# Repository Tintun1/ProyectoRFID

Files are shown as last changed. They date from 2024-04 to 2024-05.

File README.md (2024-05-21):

# Proyecto RFID/NFC con App Web

Es una solución eficaz para cuando se necesita restringir el acceso a un área determinada y queremos tener la lista de usuarios permitidos en una base de datos segura con una aplicación web para la interfaz grafica del control de acceso.

## Participantes

- Fernandez Joaquín - Programación
- Lescano Cristian - Fabricación de PCB
- Lacuadra Catalina - Montaje y diseño
- Macre Geremias -  Montaje y diseño

## Aplicación

Para implementarlo como control de acceso a un área, necesitamos ajustar unos parámetros del microcontrolador, para que se pueda conectar a la red wifi



[https://github.com/Tintun1/ProyectoRFID/blob/main/Codigo ESP32/nfcReader/nfcReader.ino](https://github.com/Tintun1/ProyectoRFID/blob/main/Codigo%20ESP32/nfcReader/nfcReader.ino)

una vez configurado, el microcontrolador ya tendrá acceso a la red wifi.

Para poder vincular nuestra base de datos lo debemos hacer desde este archivo:

[https://github.com/Tintun1/ProyectoRFID/blob/main/AppWeb/con_db.php](https://github.com/Tintun1/ProyectoRFID/blob/main/AppWeb/con_db.php)



se debería de poner las credenciales correspondientes a la base de datos y en [https://github.com/Tintun1/ProyectoRFID/blob/main/AppWeb/ESP32/esp32_update.php](https://github.com/Tintun1/ProyectoRFID/blob/main/AppWeb/ESP32/esp32_update.php)

tendremos la API de la conexión de la base de datos con el microcontrolador que se puede modificar a gusto.

Para poder hacer funcionar  la aplicación web necesitaremos hostear nuestro servidor, una de las formas es usar XAMMP que nos facilita el host de la pagina de manera local

## Usos

Luego de configurar y ajustar los parámetros a nuestra comodidad, dispondremos de un control de acceso funcional. Lo único que hay que hacer para probar que funcione correctamente es verificar si el host de la pagina anda correctamente, registrando nuestros datos en la pagina para acceder a nuestro panel admin y poder registrar tarjetas nuevas a la base de datos, una vez registrada probar si el control de acceso lee nuestra tarjeta y que de la autorización.

## Esquemático

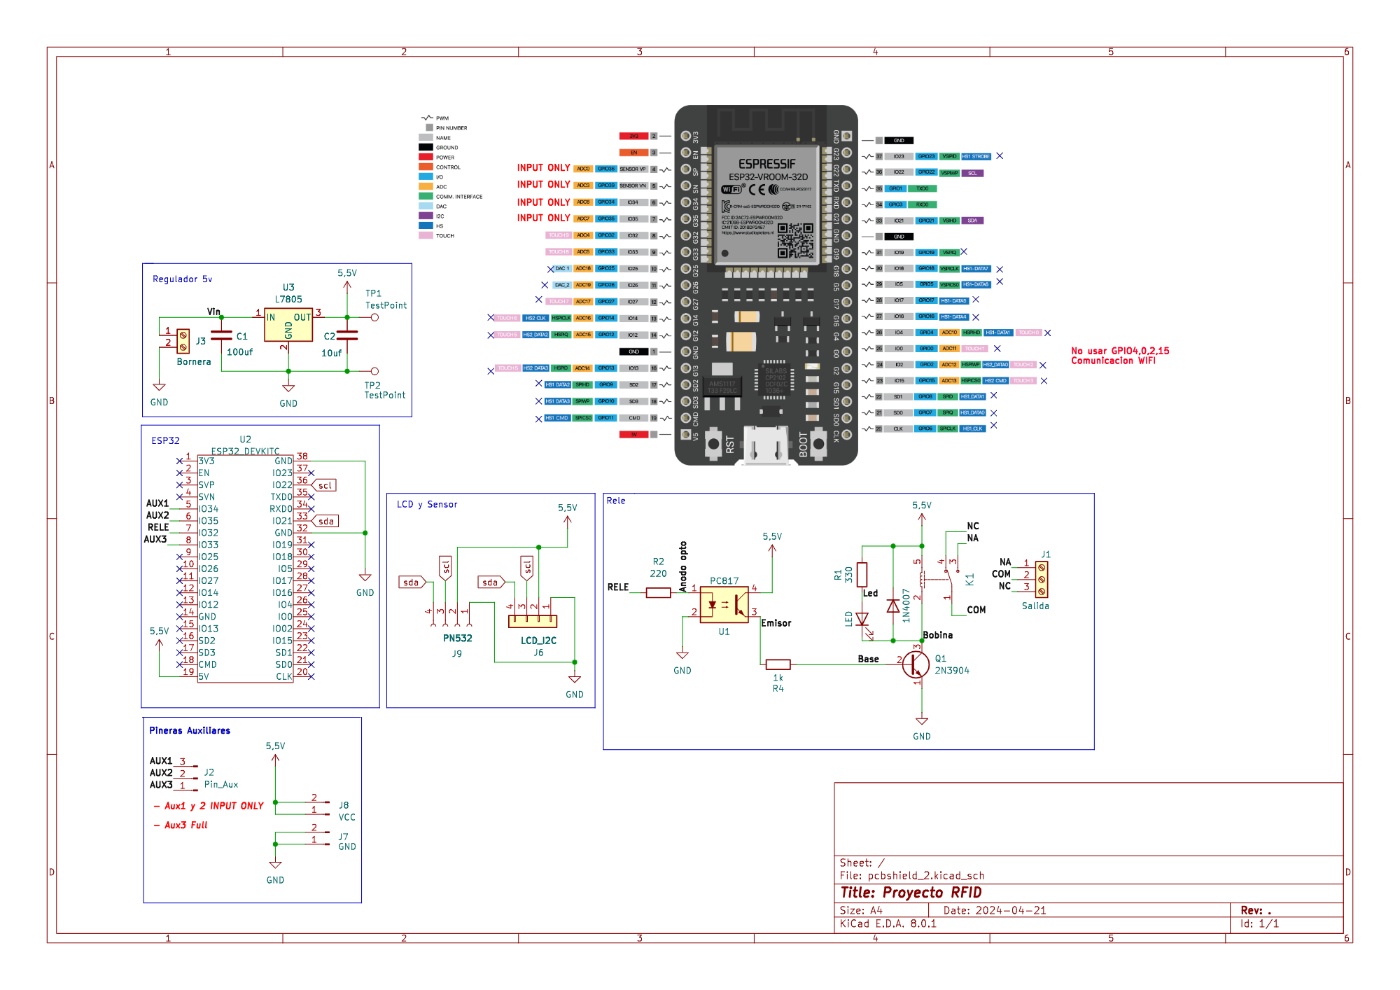
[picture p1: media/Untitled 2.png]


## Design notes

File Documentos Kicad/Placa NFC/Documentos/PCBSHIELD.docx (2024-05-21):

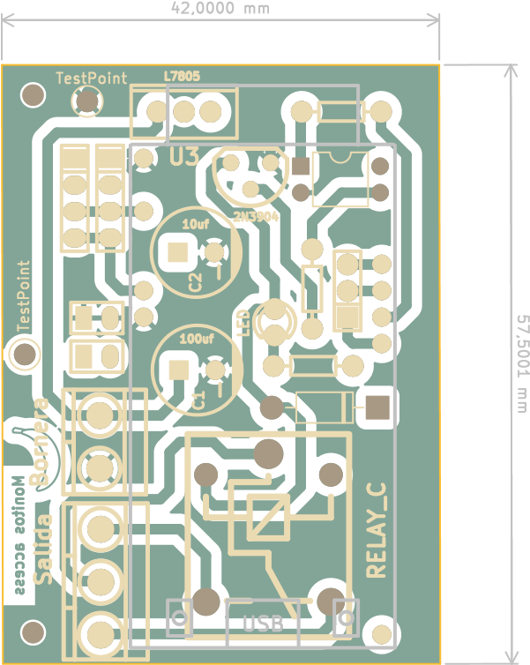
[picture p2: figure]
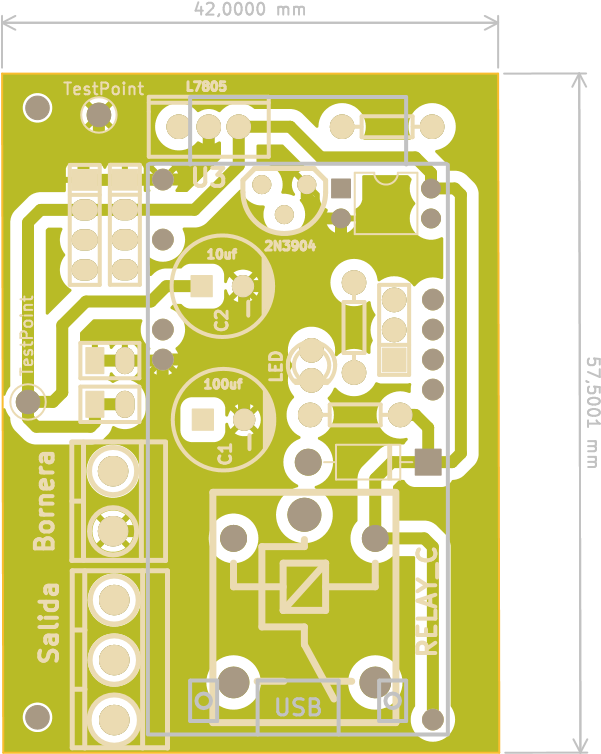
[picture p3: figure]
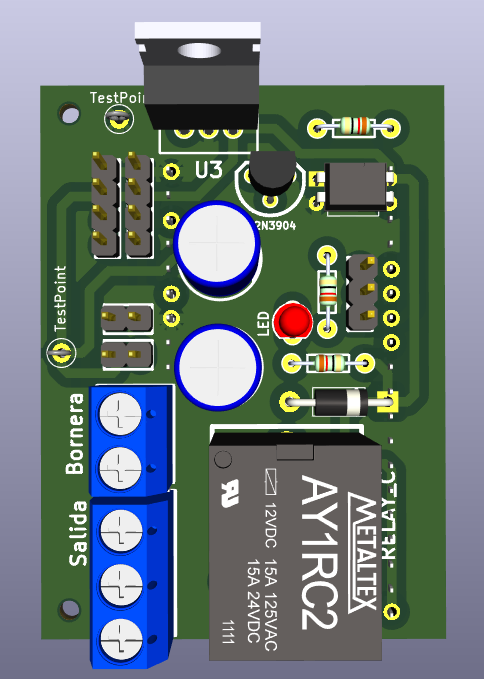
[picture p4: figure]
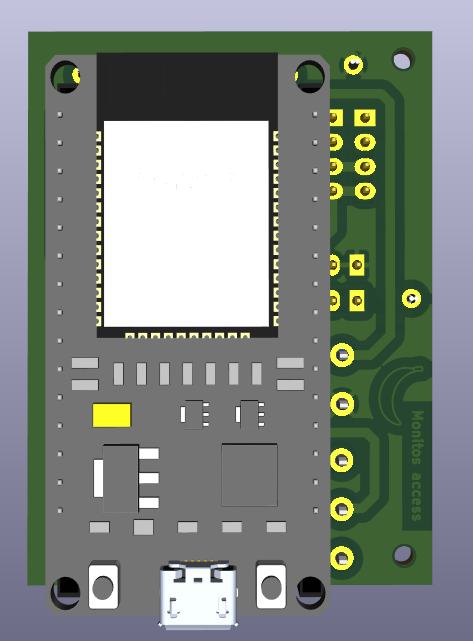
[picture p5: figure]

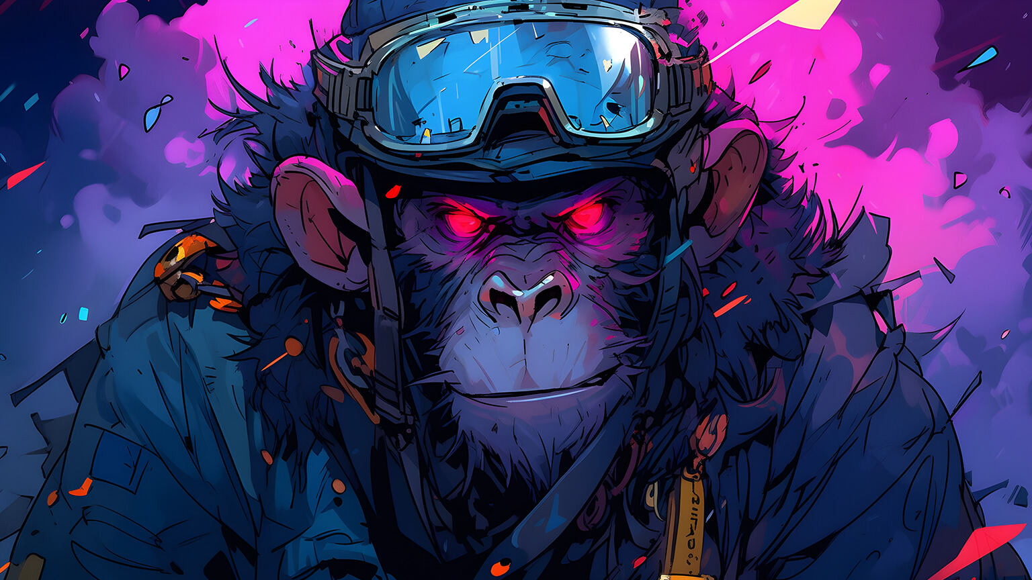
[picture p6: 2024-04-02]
AppWeb/img/monkey_background.jpg

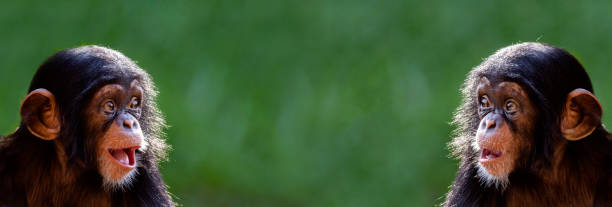
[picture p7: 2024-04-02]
AppWeb/img/input_back.jpg

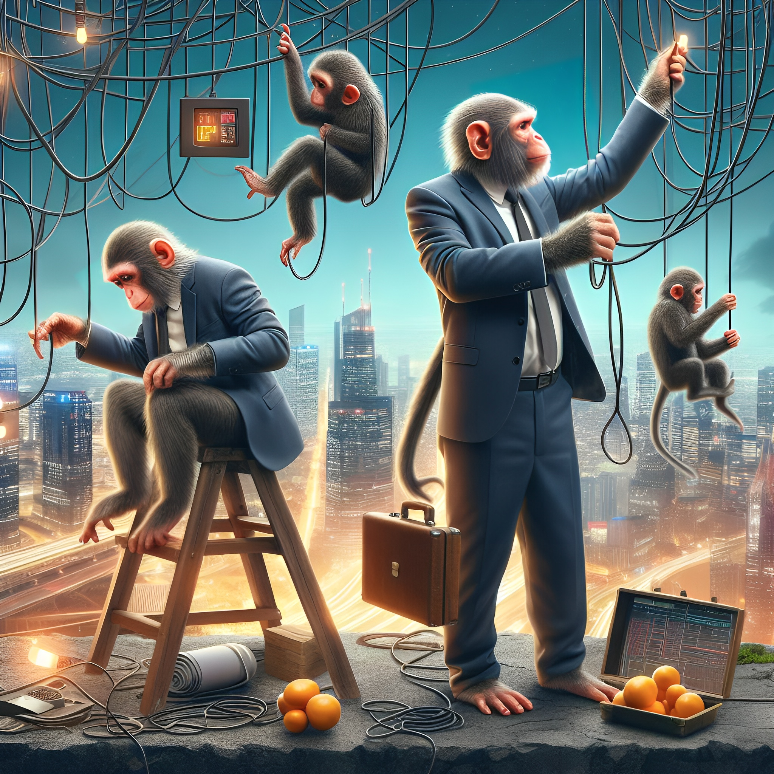
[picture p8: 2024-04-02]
AppWeb/img/background_img.jpg

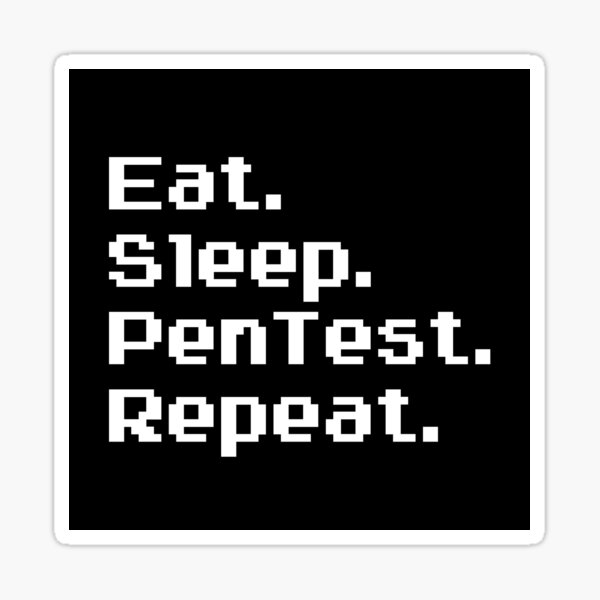
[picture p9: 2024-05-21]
AppWeb/uploads/st,small,507x507-pad,600x600,f8f8f8.u3.jpg

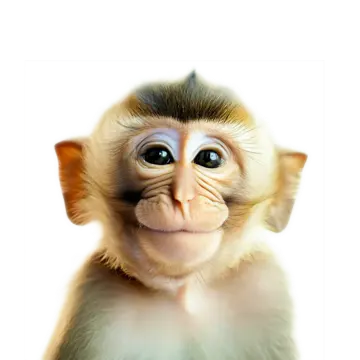
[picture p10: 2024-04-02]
AppWeb/uploads/pngtree-the-cute-monkey-on-transparent-png-image_6742881.png

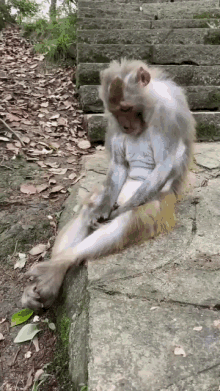
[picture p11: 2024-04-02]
AppWeb/uploads/mono-esperando_2.gif

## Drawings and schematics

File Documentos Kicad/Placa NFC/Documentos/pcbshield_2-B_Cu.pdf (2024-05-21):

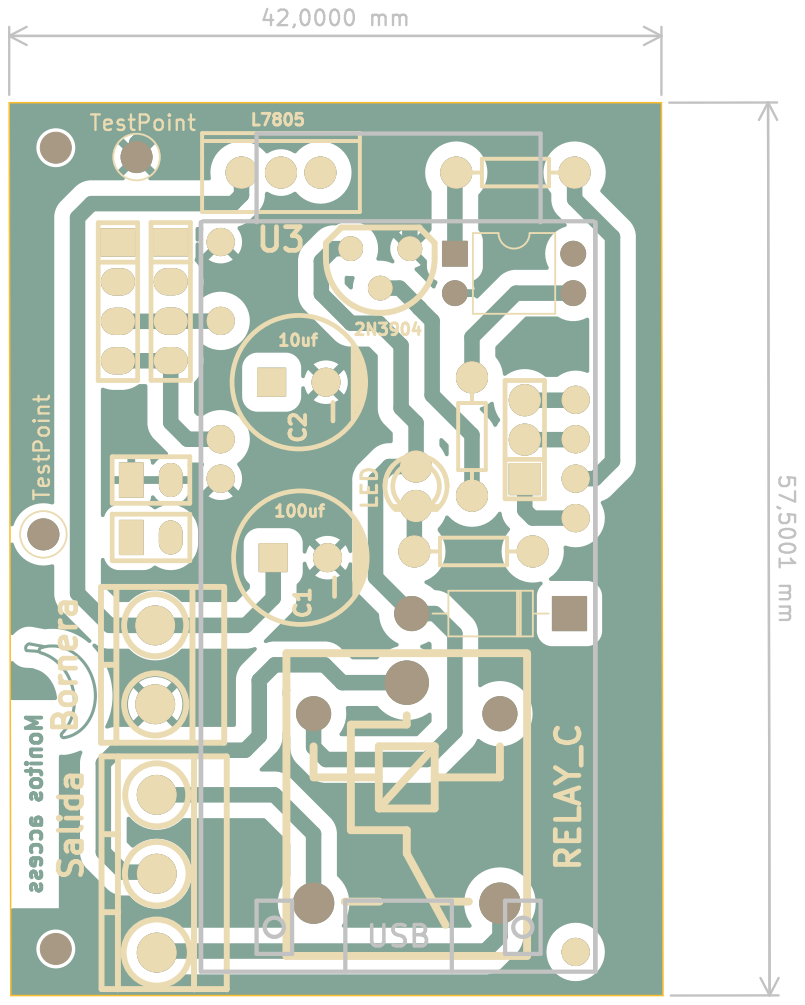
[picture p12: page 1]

Monitos access LED Salida RELAY_C C2

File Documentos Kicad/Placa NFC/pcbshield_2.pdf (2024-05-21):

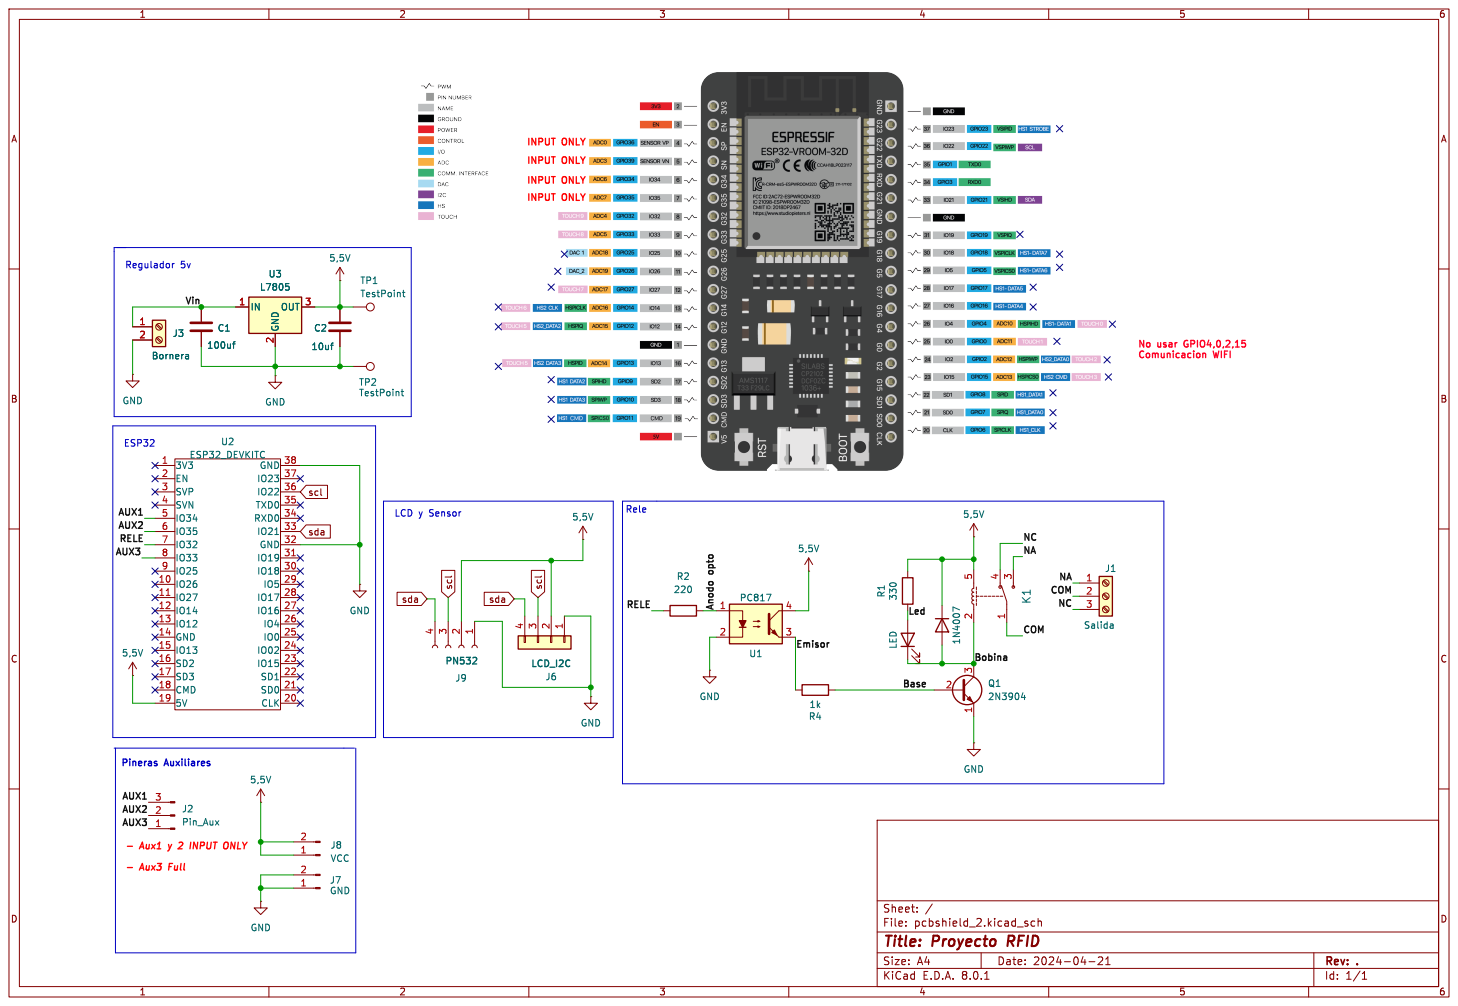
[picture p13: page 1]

Id: 1/1 Title: Proyecto RFID

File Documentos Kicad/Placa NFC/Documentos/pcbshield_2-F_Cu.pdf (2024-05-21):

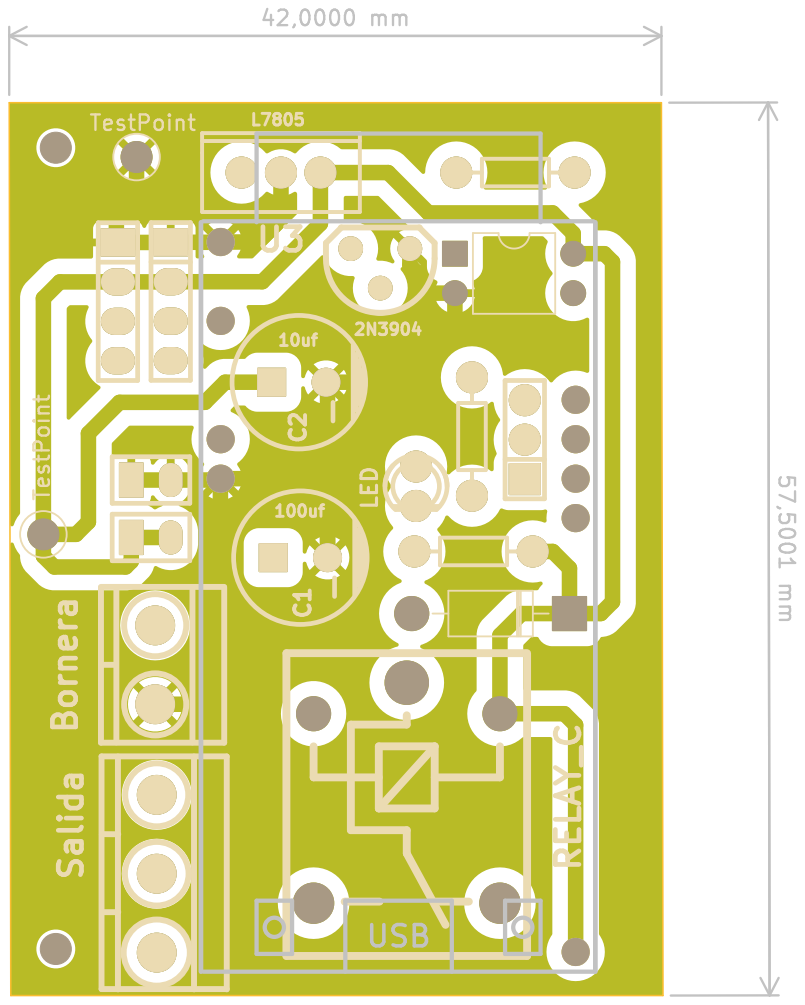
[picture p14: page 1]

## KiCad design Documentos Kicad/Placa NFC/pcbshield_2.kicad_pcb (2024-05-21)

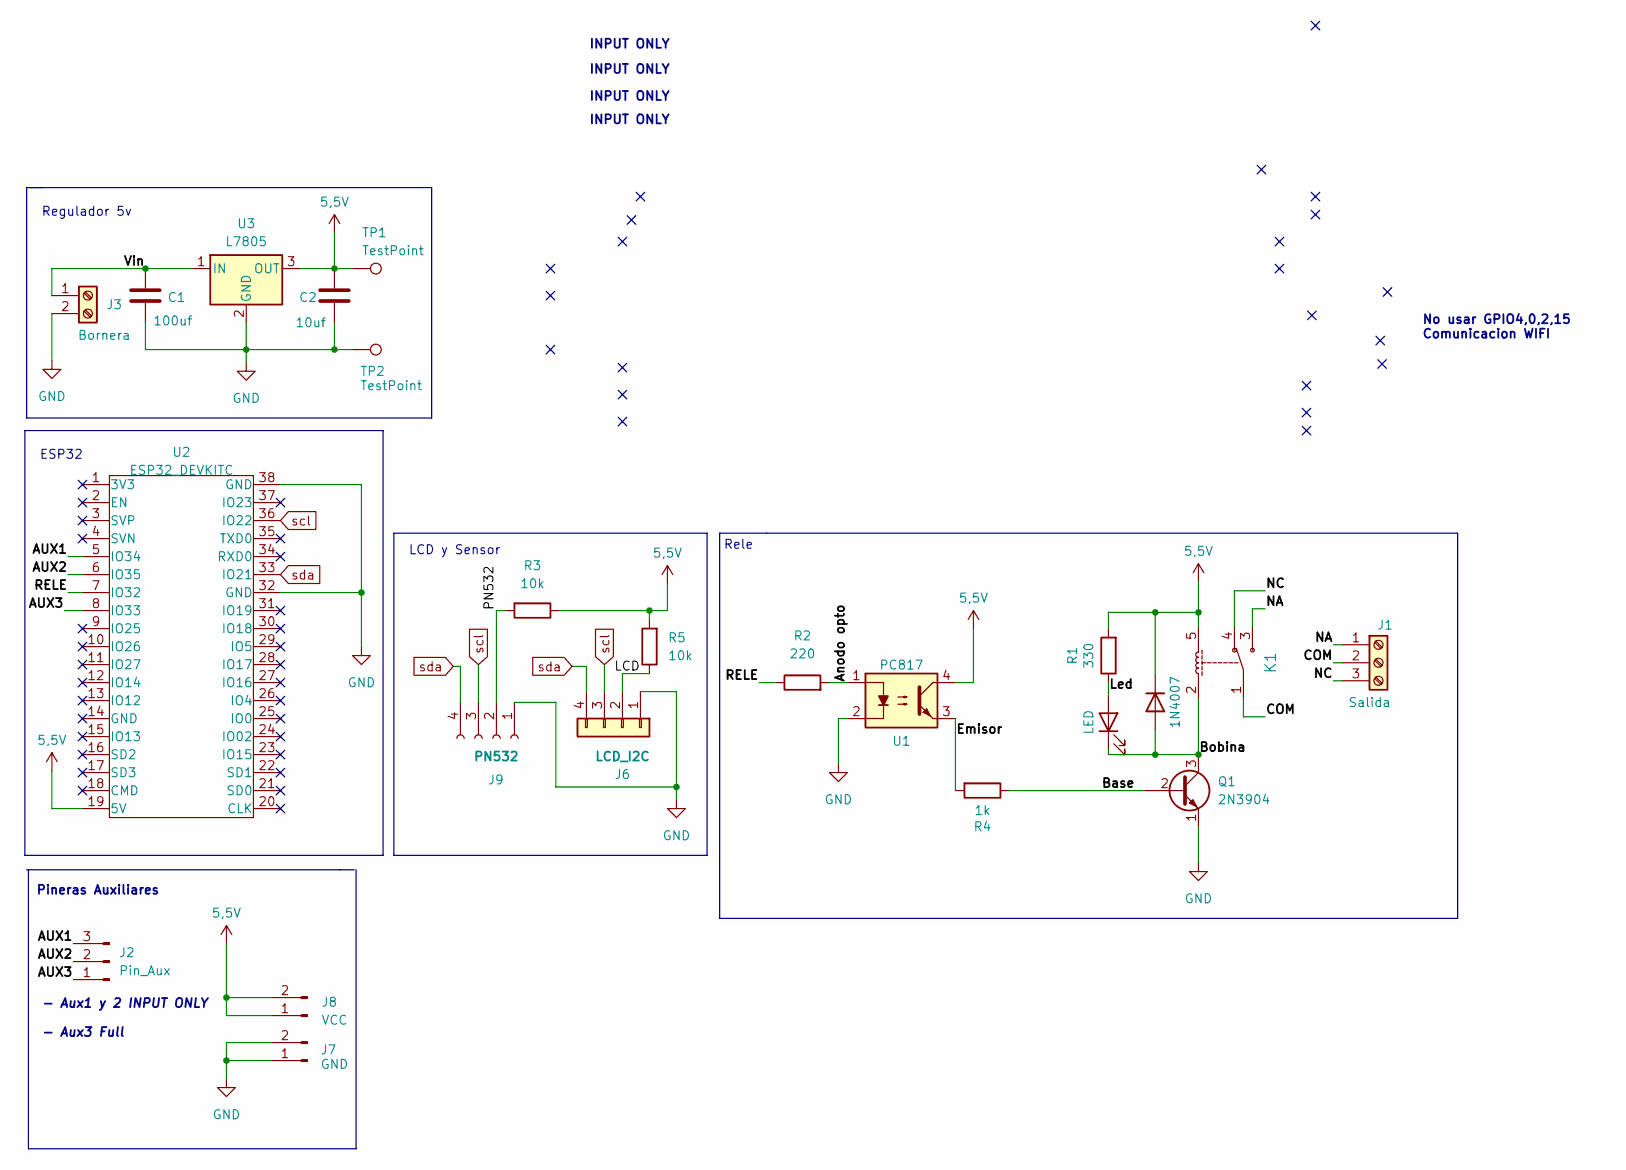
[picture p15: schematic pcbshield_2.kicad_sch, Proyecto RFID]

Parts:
C1: 100uf; CAP_ELEC_8x11.5mm
C2: 10uf; CAP_ELEC_8x11.5mm
D1: LED; led_3mm_red
D2: 1N4007; D_DO-41_SOD81_P10.16mm_Horizontal
J1: Salida; BORNERA3_AZUL
J2: Pin_Aux; Pin_Strip_3
J3: Bornera; BORNERA2_AZUL
J6: LCD_I2C; pin_strip_4
J7: GND; Pin_strip_2
J8: VCC; Pin_strip_2
J9: PN532; pin_strip_4
K1: RELAY_C; Relay_C
Q1: 2N3904; to92
R1: 330; RES0.3
R2: 220; RES0.3
R3, R5: 10k; RES0.3
R4: 1k; RES0.3
TP1, TP2: TestPoint; TestPoint_Loop_D2.50mm_Drill1.0mm_LowProfile
U1: PC817; DIP-4_W7.62mm
U2: ESP32_DEVKITC; ESP32 48x25 LEGIT
U3: L7805; TO-220

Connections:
5,5V: C2.1, D2.1 (K), J8.1, J8.2, K1.5, R1.2, R3.1, R5.2, TP1.1, U1.4, U2.19 (5V), U3.3 (OUT)
/AUX1: J2.3, U2.5 (IO34)
/AUX2: J2.2, U2.6 (IO35)
/AUX3: J2.1, U2.8 (IO33)
/Anodo opto: R2.2, U1.1
/Base: Q1.2 (B), R4.1
/Bobina: D1.1 (K), D2.2 (A), K1.2, Q1.3 (C)
/COM: J1.2, K1.1
/Emisor: R4.2, U1.3
/LCD: J6.2, R5.1
/Led: D1.2 (A), R1.1
/NA: J1.1, K1.3
/NC: J1.3, K1.4
/PN532: J9.2, R3.2
/RELE: R2.1, U2.7 (IO32)
/Vin: C1.1, J3.1, U3.1 (IN)
GND: C1.2, C2.2, J3.2, J6.1, J7.1, J7.2, J9.1, Q1.1 (E), TP2.1, U1.2, U2.32 (GND), U2.38 (GND), U3.2 (GND)
scl: J6.3, J9.3, U2.36 (IO22)
sda: J6.4, J9.4, U2.33 (IO21)

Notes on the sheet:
INPUT ONLY
Pineras Auxiliares
- Aux1 y 2 INPUT ONLY - Aux3 Full
Regulador 5v
ESP32
No usar GPIO4,0,2,15 Comunicacion WIFI
Rele
LCD y Sensor

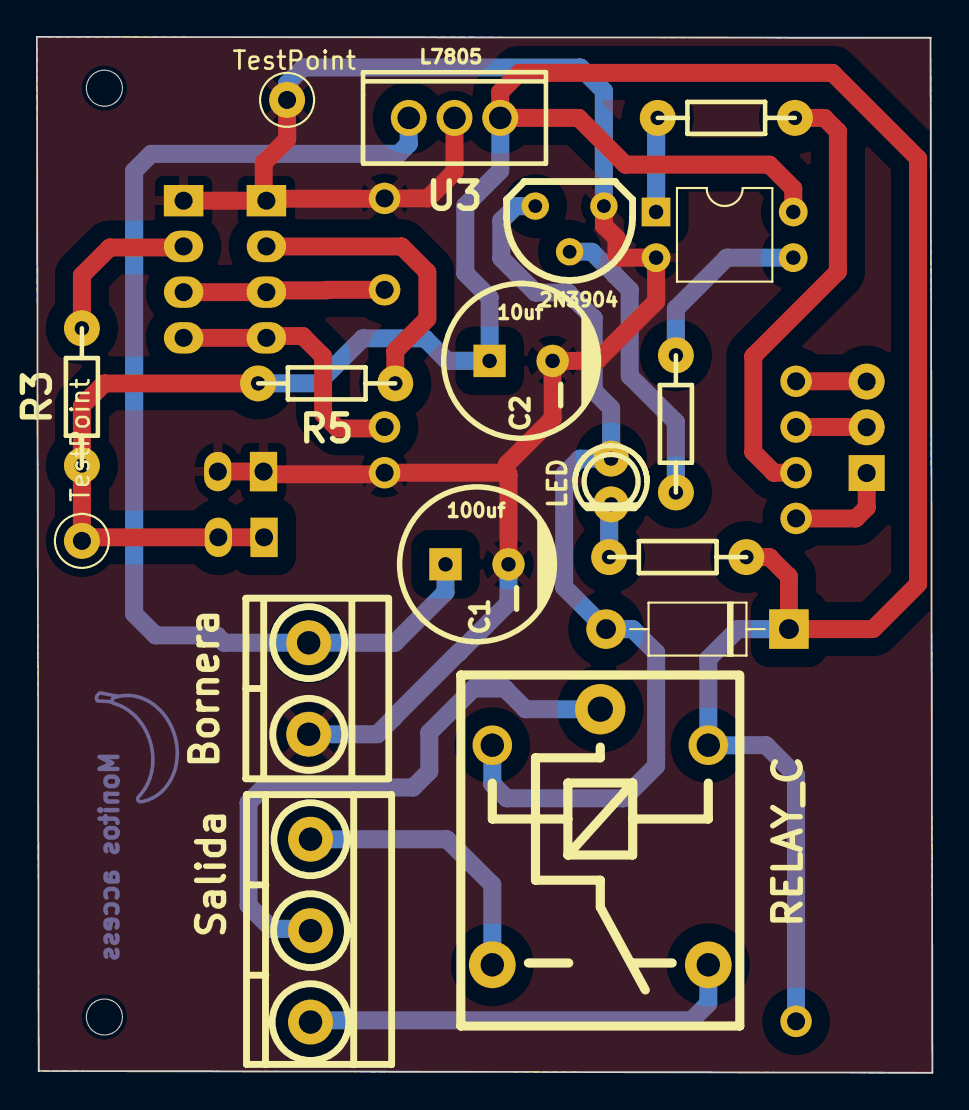
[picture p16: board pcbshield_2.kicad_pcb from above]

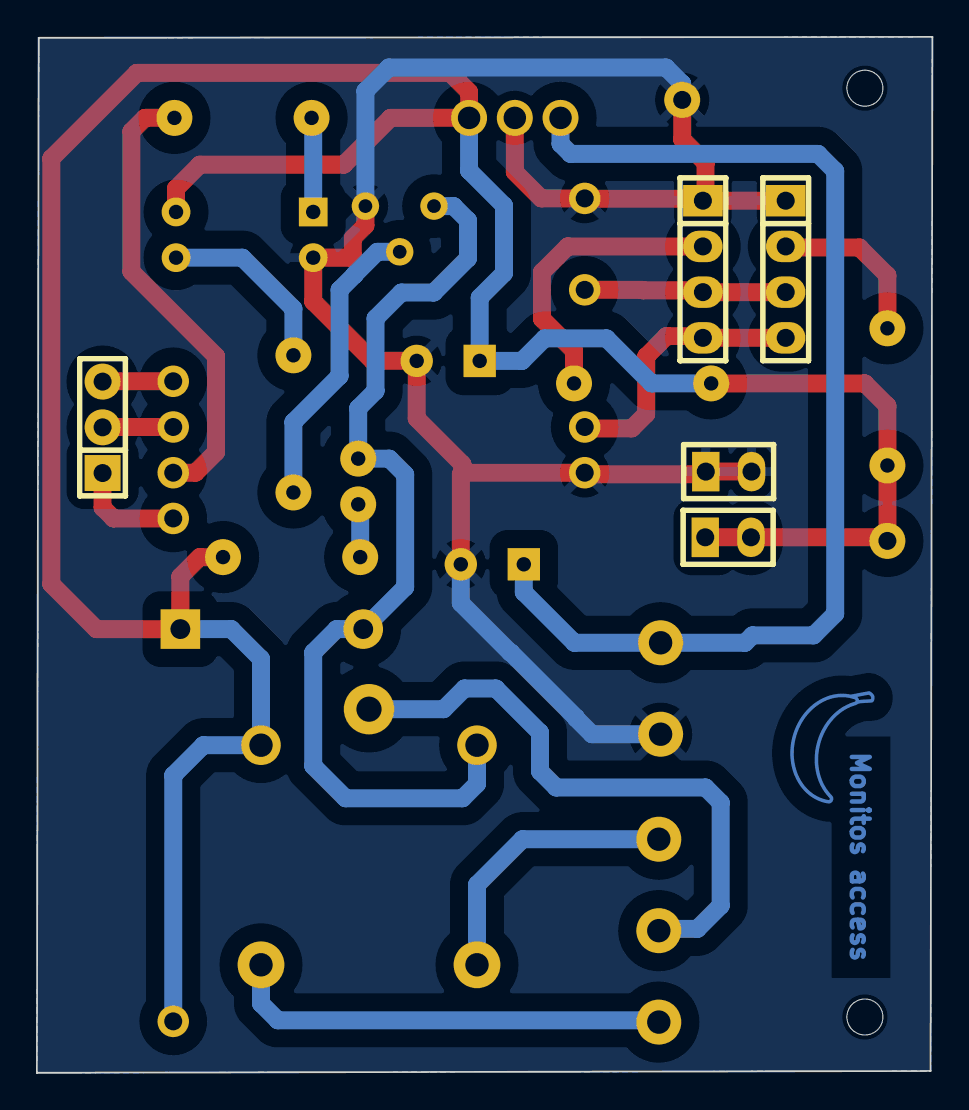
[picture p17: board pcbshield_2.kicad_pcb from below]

Board: 2 copper layers, 49.8 x 57.6 mm, 23 parts (6 on the bottom side), 19 nets.

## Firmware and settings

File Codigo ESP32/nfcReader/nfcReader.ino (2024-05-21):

#include <Wire.h>
#include <PN532_I2C.h>
#include <PN532.h>
#include <NfcAdapter.h>
#include <LiquidCrystal_I2C.h>
#include <HTTPClient.h>
#include <WiFi.h>

// Declaración del objeto lcd para controlar la pantalla LCD I2C HEX VALUE = 0x27
LiquidCrystal_I2C lcd(0x27,16,2);

// Configuración de la red WiFi
const char* ssid = "Estudiantes";
const char* password =  "educar_2018";

// Pin para el relé
const int rele = 32;

// Definición de los estados posibles del sistema
#define noAutorizado 0
#define espera 1
#define autorizado 2
#define subiendo 3
#define subido 4

// Inicialización de variables de estado
bool estado_rele = false;
int estado_Tarjeta = espera;
int estado_uid = espera;

// Variables para el manejo de tiempo
unsigned long tiempo_actual;
unsigned long tiempo_anterior = 0;

// Inicialización del objeto NFC
PN532_I2C pn532_i2c(Wire);
NfcAdapter nfc = NfcAdapter(pn532_i2c);
String tagId = "None";
byte nuidPICC[4];

// Configuración inicial del sistema
void setup(void) {
  // Inicialización y encendido del LCD
  lcd.init();
  lcd.backlight();
  lcd.setCursor(0,0);
  lcd.print("Iniciado");

  // Inicialización de la comunicación serial
  Serial.begin(115200);
  Serial.println("System initialized");

  // Configuración del pin del relé como salida
  pinMode(rele, OUTPUT);

  // Inicialización del módulo NFC
  nfc.begin();

  // Conexión a la red WiFi
  WiFi.begin(ssid, password);
  
  Serial.print("Conectando...");
  while (WiFi.status() != WL_CONNECTED) {
    delay(500);
    Serial.print(".");
  }

  Serial.print("Conectado con éxito, mi IP es: ");
  Serial.println(WiFi.localIP());
}

// Función principal del programa
void loop(void) {
  // Comprobación de la conexión WiFi
  if(WiFi.status()== WL_CONNECTED){
    HTTPClient http;
    
    http.begin("http://10.0.9.125/ProyectoRFID/esp32/esp32_update.php");
    http.addHeader("Content-Type", "application/x-www-form-urlencoded");

    // Refrescar el tiempo actual
    tiempo_actual = millis();

    // Comprobación y manejo de estados
    if (estado_rele && estado_Tarjeta == autorizado) {
      resetEstado(4000);
    }

    if (!estado_rele && estado_Tarjeta == espera) {
      // Configuración de la pantalla LCD y espera de tarjeta
      lcd.clear();
      lcd.setCursor(0,0);
      lcd.print("Cerrado");
      lcd.setCursor(0,1);
      lcd.print("Apoyar tarjeta");
      digitalWrite(rele, LOW);

      // Lectura de la tarjeta NFC
      if (nfc.tagPresent()) {
        NfcTag tag = nfc.read();
        Serial.println("ID:" + tag.getUidString());

        // Envío de la UID al servidor para comprobación
        int codigo_respuesta = http.POST("check_uid_code=" + tag.getUidString());
        if (codigo_respuesta == 200){
          String mensaje_respuesta = http.getString();
          Serial.println("Servidor responde:" + mensaje_respuesta);
          if (tag.getUidString() == mensaje_respuesta){
            actualizarEstado(autorizado);
          } else {
            actualizarEstado(noAutorizado);
          }
        } else {
          Serial.println("Error al mandar el POST verificativo");
        }
      }

      // Verificación del estado de la tarjeta en el servidor
      int codigo_respuesta2 = http.POST("check_uid_status=1");
      if (codigo_respuesta2 == 200){
        String mensaje_respuesta2 = http.getString();
        Serial.println("Servidor responde al estado:" + mensaje_respuesta2);
        if (mensaje_respuesta2 == "1"){
          estado_Tarjeta = subiendo;
          lcd.clear();
          lcd.setCursor(0,0);
          lcd.print("Acerque tarjeta");
          lcd.setCursor(0,1);
          lcd.print("Para registro");
        }
      } else {
        Serial.println("Error al mandar el POST verificativo");
      }
    }

    if (estado_Tarjeta == noAutorizado){
      // Acciones a realizar si la tarjeta no está autorizada
      resetEstado(4000);
    }

    if (estado_Tarjeta == subiendo){
      // Acciones a realizar si la tarjeta está en proceso de subida al servidor
      if (nfc.tagPresent()) {
            NfcTag tag = nfc.read();
            Serial.println("ID:" + tag.getUidString());
            int codigo_respuesta3 = http.POST("submit_uid=" + tag.getUidString());

            if (codigo_respuesta3 == 200){
              lcd.clear();
              lcd.setCursor(0,0);
              lcd.print("Subido");
              actualizarMillis();
              estado_Tarjeta = subido;
            }
          }
    }

    if (estado_Tarjeta == subido){
      // Acciones a realizar si la tarjeta ya ha sido subida al servidor
      resetEstado(2000);
    }
    http.end(); // Liberación de recursos
  }
}

// Función para reiniciar los estados del sistema
void resetEstado(unsigned long tiempo_espera) {
  if (tiempo_actual - tiempo_anterior >= tiempo_espera){
    tiempo_anterior = tiempo_actual;
    estado_rele = false;
    estado_Tarjeta = espera;
    Serial.println("Reset");
  }
}

// Función para actualizar el tiempo actual
void actualizarMillis(){
  tiempo_actual = millis();
  tiempo_anterior = tiempo_actual;
}

// Función para actualizar el estado del sistema y mostrarlo en la pantalla LCD
void actualizarEstado(int nuevo_estado) {
  lcd.clear();
  lcd.setCursor(0,0);
  estado_Tarjeta = nuevo_estado;
  tiempo_actual = millis();
  tiempo_anterior = tiempo_actual;
  if (nuevo_estado == autorizado) {
    lcd.print("Autorizado");
    estado_rele = true;
    digitalWrite(rele, HIGH);
  } else {
    lcd.print("No autorizado");
  }
}

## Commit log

2024-04-09 pcb
    pcb y esquematico
    [rele-1.kicad_pcb, rele-1.kicad_sch]
2024-04-10 pcb update
    3d model
    [rele-1.kicad_pcb, rele-1.kicad_sch]
2024-04-13 PCB 2
    pcb doble faz
    [pcbshield_2.kicad_pcb, pcbshield_2.kicad_sch]
2024-05-21 Actualizacion
    -Codigo de esp32 funcionando
    -Placa necesita correcciones,pero funciona
    -AppWeb funcionando
    [pcbshield_2.kicad_pcb, pcbshield_2.kicad_sch, rele-1.kicad_pcb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]
